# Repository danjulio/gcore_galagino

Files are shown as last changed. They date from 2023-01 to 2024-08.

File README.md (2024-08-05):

# Galagino ported to gCore
This repo is a fork of Till Harbaum's awesome [Galaga emulator](https://github.com/harbaum/galagino) ported to [gCore](https://github.com/danjulio/gCore).  It runs really well.

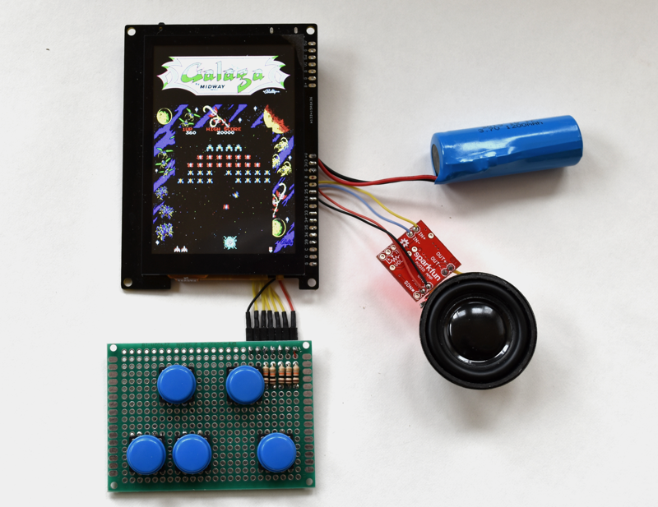
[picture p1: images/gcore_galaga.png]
Galaga on gCore


I made the following changes.

1. Changed from ILI9341 LCD driver in video.c to use my port of TFT_eSPI.
2. Changed GPIO pins for buttons (see below).
3. Added a background image around the play field.
4. Added a FAST\_FPS define to config.h to try for 60 FPS updates instead of the default 30 FPS (looked at in galingo.ino).  Add LOG\_FPS define which enables logging FPS values to the serial port.
5. Detect fast press of gCore power button to power down.
6. A little cleanup.

Compiled on Arduino 1.8.19 with ESP32 Arduino package 2.0.6.  You'll need the following libraries installed and to follow Till's original instructions below which include downloading the Z80 emulator, and finding and downloading the Galaga ROM files, then running his scripts to process them.

1. My version of [TFT_eSPI](https://github.com/danjulio/TFT_eSPI).
2. Arduino [gCore](https://github.com/danjulio/gCore/tree/main/Arduino/gCore) library.  Can also be directly downloaded from my [website](https://danjuliodesigns.com/products/gcore.html).
3. Adafruit_GFX_Library

Set the board type to WROOM.  This is to force all memory allocations to occur to ESP32 internal memory (external PSRAM is too slow for the emulator).

The hookup diagram is shown below.  You can put the buttons on a proto board as I did or you can use a breadboard as Till did.  External pull-up resistors are required since I am using GPIO34-39 (10 k-ohm is fine).  I used an [amp breakout board](https://www.sparkfun.com/products/11044) from Sparkfun but only because I had it laying around.  You can also use the amp boards Till mentions.

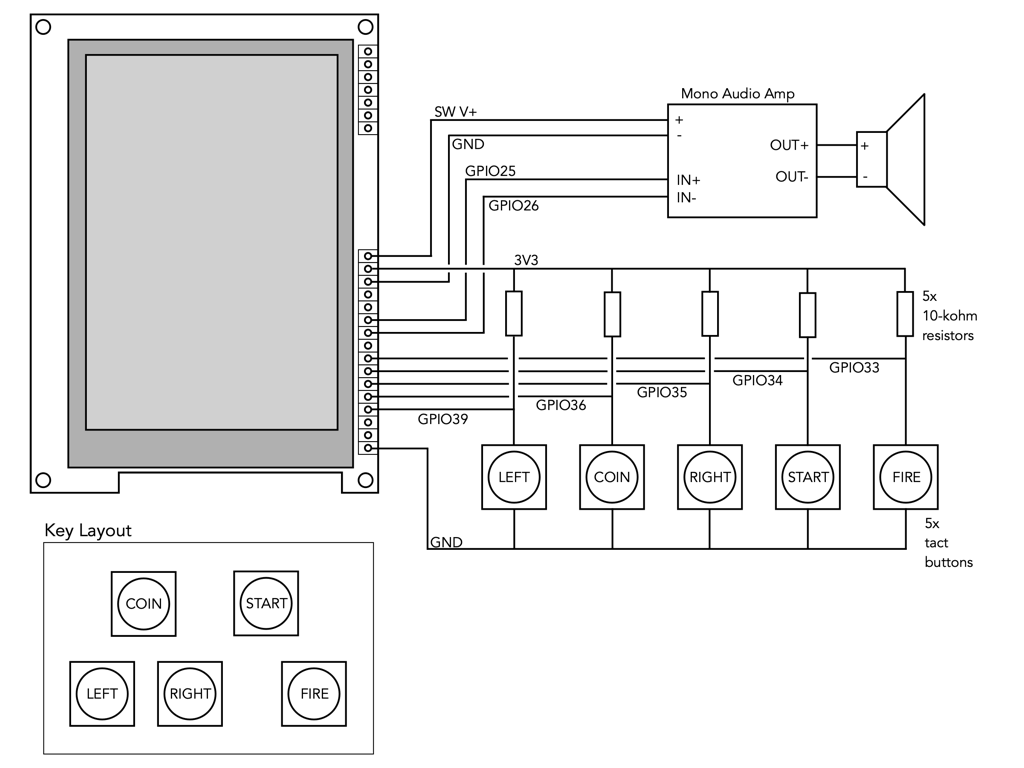
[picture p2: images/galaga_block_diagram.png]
gCore Galaga hookup diagram


## Enclosure
I used OpenSCAD to make a basic enclosure for my build.  The OpenSCAD source and STL files are in the ```enclosure``` directory.

The design also includes support for a bit of extra hardware.

1. Bulkhead USB-C connector connected to gCore's +5/GND inputs
2. Bulkhead Power button connected to gCore's SW/GND inputs
3. Bulkhead slide switch connected in series with the Audio Amp SW V+ to allow turning off the sound

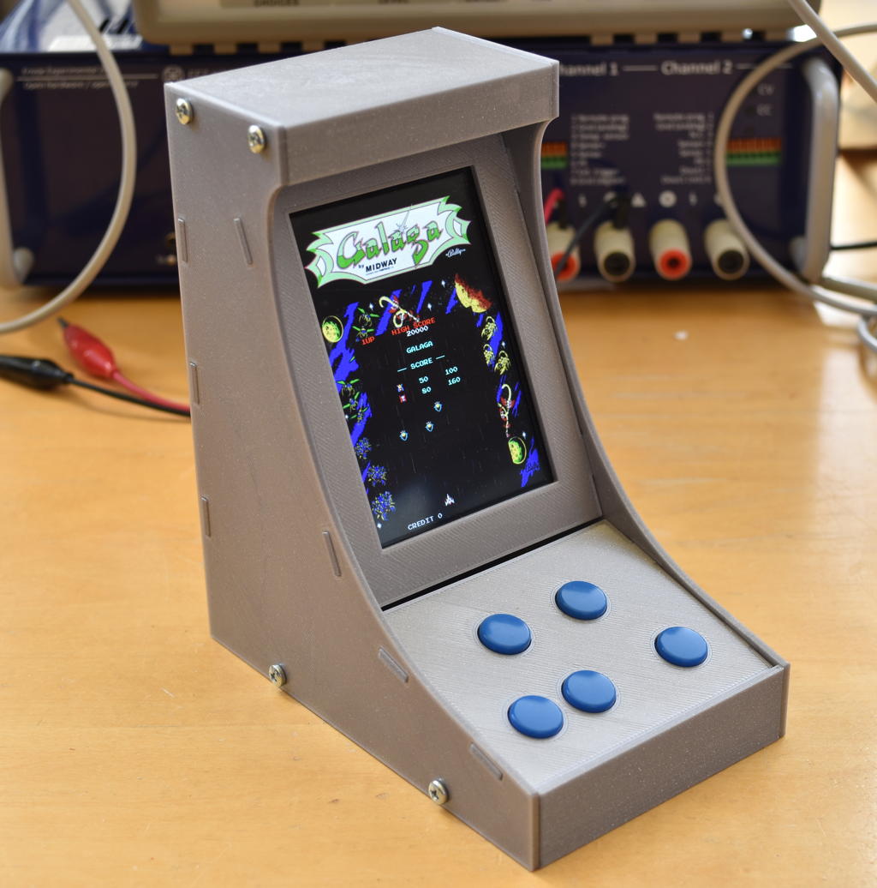
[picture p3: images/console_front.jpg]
Enclosure Front


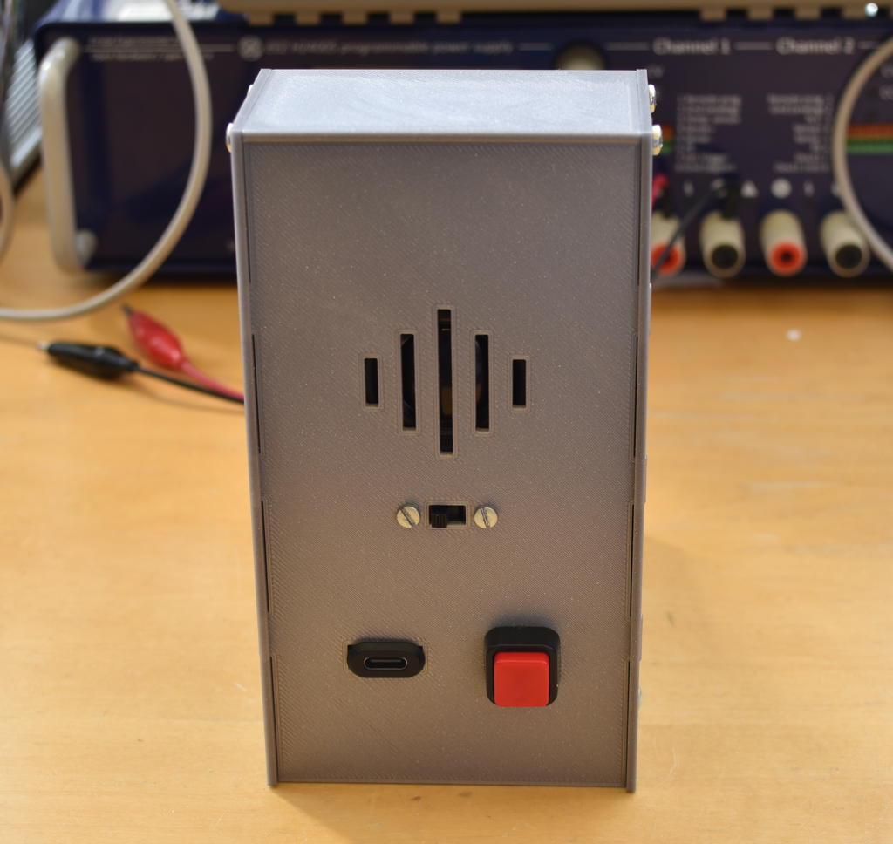
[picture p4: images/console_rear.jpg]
Enclosure Rear


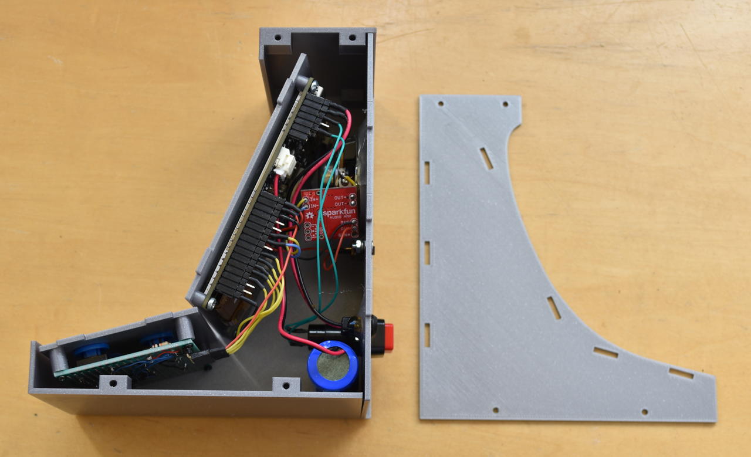
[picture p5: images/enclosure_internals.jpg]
Enclosure internals


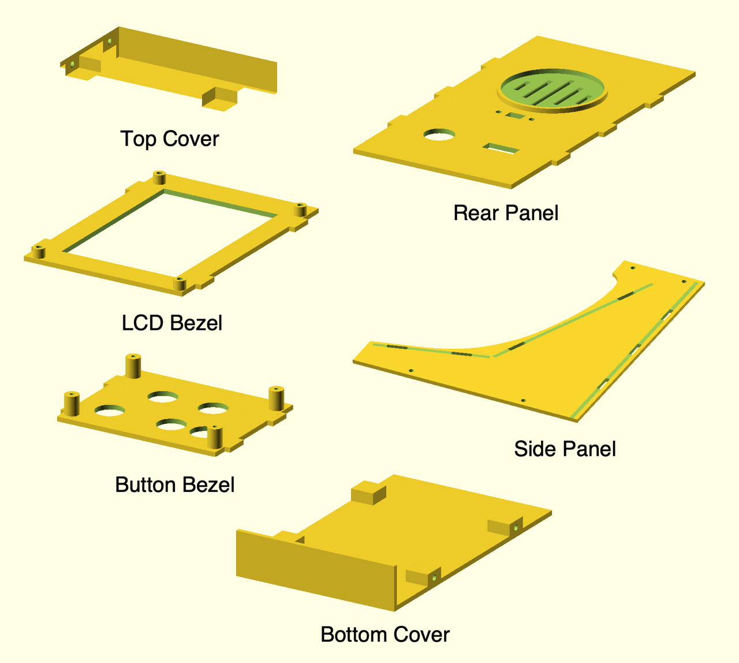
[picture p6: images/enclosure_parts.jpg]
OpenSCAD parts


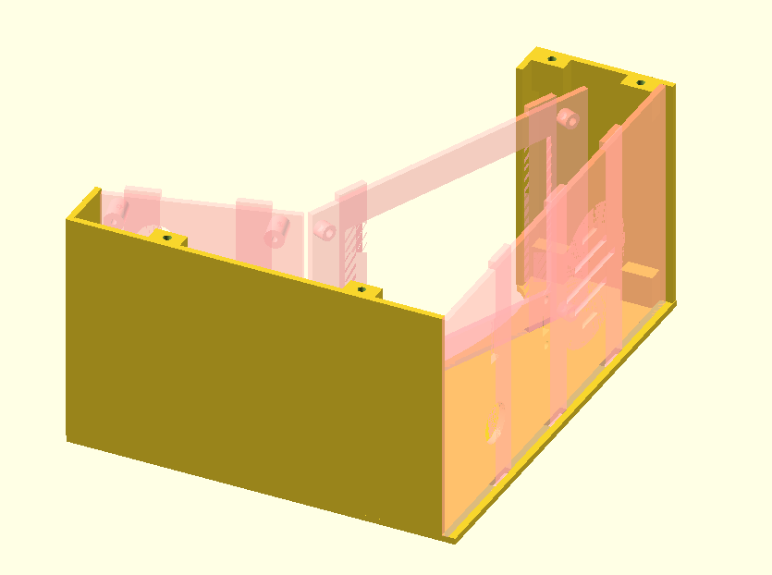
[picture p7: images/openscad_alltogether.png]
OpenSCAD altogether image


# Till Harbaum's Original Readme Below
## Galaga arcade emulator for ESP32

Galagino screencast

[Galaga](https://de.wikipedia.org/wiki/Galaga) is one of the most iconic arcade machines of all times. It has
been remade and emulated many times. So far the cheapest and smallest
system able to do a faithful emulation of the original arcade machine
was the raspberry pi. But even the much cheaper ESP32 should be able
too easily emulate a machine from the early 80's, shouldn't it?

Well, things are not that easy. The galaga arcade was driven by three
Z80 CPUs, each running at 3Mhz. Additionally the arcade machine
included two more CPUs for button and coin handling and for audio
support. And finally the hardware itself had dedicated support
for simple wavetable audio, tilemap graphics and up to 64 sprites.
The video resolution was 224 by 288 pixels. The ESP32 on the other hand
comes with two cores running at 240MHz. But it lacks dedicated video
hardware. Emulating the various CPUs as well as the handling of
audio and graphics turned out to be challenging for the ESP32.

Cheap TFT screens with a resolution of 320 by 240 pixels are available
in various sizes from 2.0 inch to 3.2 inch allowing for a very small
and cheap *galagino* setup.

These small displays usually allow for SPI clock rates of up to 40MHz
allowing for a max screen refresh rate of ~30Hz. This is exactly half
the refresh rate of the original arcade machine. 30Hz is sufficient
for a very fluid gameplay.

## Youtube videos

* [First test](https://www.youtube.com/shorts/LZRI6izM8XM)
* [Sound and Starfield working](https://www.youtube.com/shorts/8uNSv0aRtgY)
* [Finally playable](https://www.youtube.com/shorts/wqnJzOAAths)
* [Pac-Man on Galagino](https://www.youtube.com/shorts/F4-XiiPwG1c)

## Hardware

The hardware is built around one of those cheap ESP32 development
boards like the ESP32 Devkit V4 depicted in the images below. The
components needed are:

* ESP32 development board (e.g. [Devkit V4](https://www.espressif.com/en/products/devkits/esp32-devkitc))
* A 320x240 SPI TFT screen (no touch needed)
  * Either a ILI9341 based screen as depicted, or
  * a ST7789 based screen with 320x240 pixels
* An audio amplifier and speaker
  * e.g. a [PAM8302A](https://www.adafruit.com/product/2130) and a 3W speaker (as seen in the photos), or
  * a [Keyestudio SC8002B](https://www.keyestudio.com/products/keyestudio-sc8002b-audio-power-amplifier-speaker-module-for-arduino-player), or similar
* five push buttons
* breadboard and wires

The entire setup should be connected as depicted below. The Devkit is
too wide for the breadboard leaving no space above it to connect
wires. Thus the wires going to the top pin row of the Devkit are
placed underneath the DevKit with the connections done as shown in the
image below.

Breadboard scheme

Download as [Fritzing](images/galagino_bb.fzz) or [PDF](images/galagino_bb.pdf)

Breadboard photo

## Software

The software consists of three parts:

* The [Galagino specific code](galagino/) contained in this repository
* The [original Galaga Namco Rev. B ROM files](https://www.bing.com/search?q=galaga+namco+b+rom)
* A [Z80 software emulation](https://fms.komkon.org/EMUL8/Z80-081707.zip)

The ROM files have to be placed in the [roms directory](roms/), together with
the ZIP file containing the Z80 emulator. A set of [python scripts](romconv/)
is then being used to convert and patch the ROM data and emulator code and
to include the resulting code into the galagino sketch directory. These
scripts need to be run like so (this has yet only been tested under Linux,
feedback for Windows is welcome):

```
$ cd romconv
$ ./audioconv.py > ../galagino/wavetables.h
$ ./cmapconv.py > ../galagino/colormaps.h
$ ./romconv.py > ../galagino/rom.h
$ ./spriteconv.py > ../galagino/spritemap.h
$ ./tileconv.py > ../galagino/tilemap.h
$ ./tileaddr.py > ../galagino/tileaddr.h
$ ./starsets.py > ../galagino/starseed.h
$ ./z80patch.py 
Copying CodesCB.h
Copying Codes.h
Copying CodesXX.h
Copying CodesED.h
Copying CodesXCB.h
Copying Tables.h
Patching Z80.h
Patching Z80.c
$
```

Afterwards the [galagino directory](galagino) should contain the following files:

```
CodesCB.h    Codes.h      CodesXX.h    config.h     emulation.h
rom.h        starseed.h   tileaddr.h   video.cpp    wavetables.h
Z80.h        CodesED.h    CodesXCB.h   colormaps.h  emulation.c
galagino.ino spritemap.h  Tables.h     tilemap.h    video.h
Z80.c
```

With all these files in place, the galagino.ino sketch can be loaded
into the [Arduino IDE](https://docs.arduino.cc/software/ide-v2). The
Arduino IDE must have the [ESP32 board support](https://github.com/espressif/arduino-esp32)
installed and the appropriate board like e.g. the
*ESP32 Dev Module* should be selected. Finally the default core used
by Arduino should be 1 (this is the default) as Galagino will use core 0
for audio and video emulation.

## Configuration

The Galagino code can be configured through the [galagino/config.h](galagino/config.h)
file. This is also the place where it's possible to choose between the ILI9143
controller (default) and the ST7789.

Also the pin assignment can be adjusted or the TFT SPI clock.

## Improvements

Galagino runs fluid and plays perfectly. Still a few things could be optimized.

* Displays allowing for 80MHz SPI clock could run the video at full 60Hz
* The SPI display update could be done using DMA which would significantly reduce the load on ESP32 core 0
* VGA output could be used to drive a VGA screen
* The ESP32's bluetooth could be used to connect to a wireless gamepad
* Galagino could be ported to the [Raspberry Pi Pico and the DVI sock](https://picockpit.com/raspberry-pi/raspberry-pi-pico-video-output/)

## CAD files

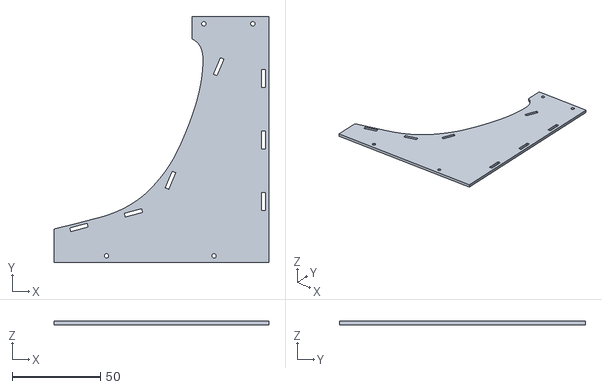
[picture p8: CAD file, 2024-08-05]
enclosure/galaga_side.stl
122.0 x 139.7 x 2.00

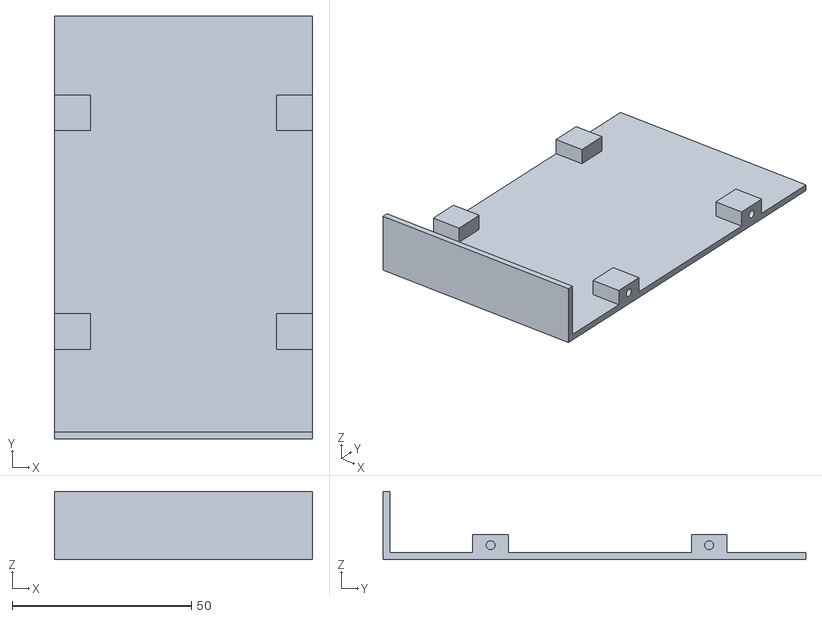
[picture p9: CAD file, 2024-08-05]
enclosure/galaga_base.stl
72.0 x 118.0 x 19.0

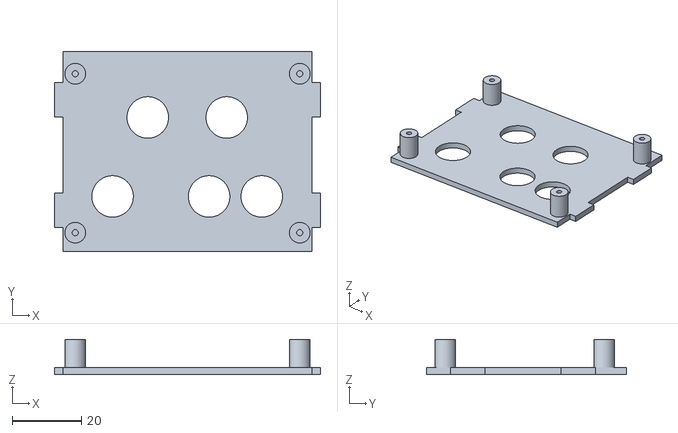
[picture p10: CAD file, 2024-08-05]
enclosure/galaga_button.stl
77.0 x 58.0 x 10.2

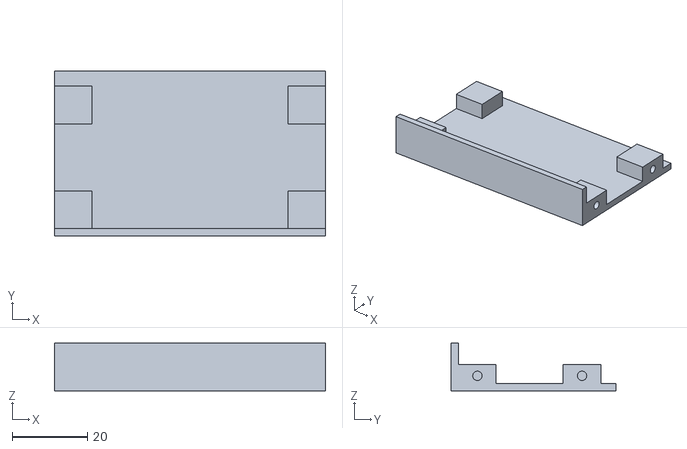
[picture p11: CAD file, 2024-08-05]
enclosure/galaga_lid.stl
72.0 x 43.8 x 12.7

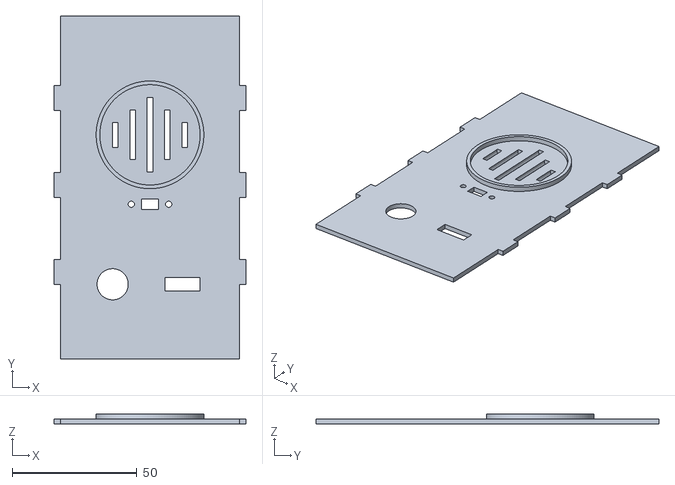
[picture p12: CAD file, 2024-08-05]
enclosure/galaga_rear.stl
77.0 x 137.7 x 4.00

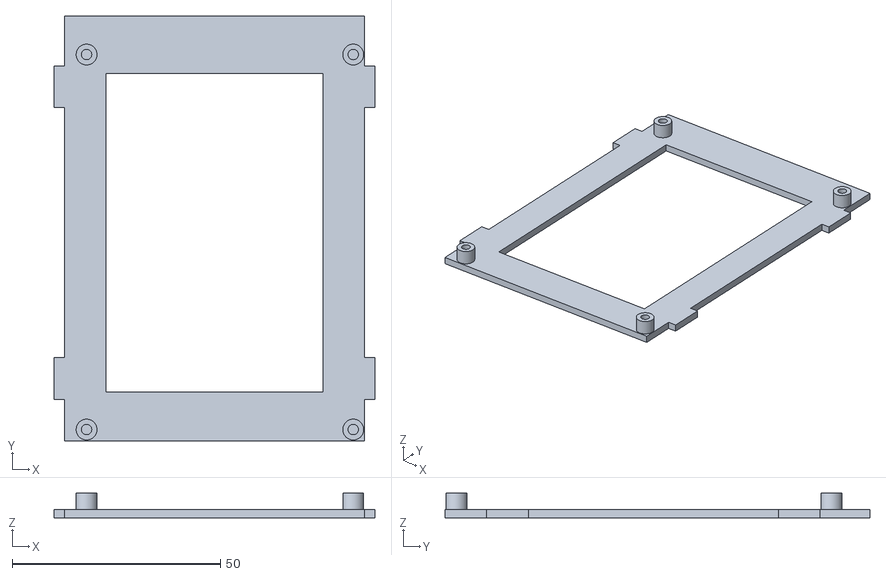
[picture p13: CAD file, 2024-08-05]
enclosure/galaga_lcd.stl
77.0 x 102.0 x 6.00

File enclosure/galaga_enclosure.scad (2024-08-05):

//
// Galaga Enclosure
//

// Render modes
//   1 raw_case_side
//   2 button_bezel
//   3 lcd_bezel
//   4 rear_panel
//   5 base
//   6 lid
//   7 case_side
//   8 all_together (one side + all other walls)
//
render_mode = 8;


module raw_case_side() {
    linear_extrude(height=2, center=false, convexity=10) {
        import(file = "case_side.svg", center=false, dpi=72);
    }
}


// PCB: 70 x 50 -> 72 x 58 (2 extra at lcd_bezel end);  Holes: 1.25 + 0.5*2.5 = 2.5
module button_bezel(slot_extra) {
    difference() {
        union() {
            cube([72, 58, 2]);
            
            // mounting tabs
            translate([-2.5, 7 - slot_extra, 0 - slot_extra]) {
                cube([77, 10 + 2*slot_extra, 2 + 2*slot_extra]);
            }
            
            translate([-2.5, 39 - slot_extra, 0 - slot_extra]) {
                cube([77, 10 + 2*slot_extra, 2 + 2*slot_extra]);
            }
            
            // Stand-offs
            translate([3.5, 5.5, 0]) {
                cylinder(r=3, h=2+8.2, $fn=120);
            }
            
            translate([72 - 3.5, 5.5, 0]) {
                cylinder(r=3, h=2+8.2, $fn=120);
            }
            
            translate([3.5, 55 - 3.5, 0]) {
                cylinder(r=3, h=2+8.2, $fn=120);
            }
            
            translate([72 - 3.5, 55 - 3.5, 0]) {
                cylinder(r=3, h=2+8.2, $fn=120);
            }
        }
        
        // screw holes
        translate([3.5, 5.5, 2]) {
            cylinder(r=0.9, h=2+ 8.3, $fn=120);
        }
        
         translate([72 - 3.5, 5.5, 2]) {
            cylinder(r=0.9, h=2+ 8.3, $fn=120);
        }
        
         translate([3.5, 55 - 3.5, 2]) {
            cylinder(r=0.9, h=2+ 8.3, $fn=120);
        }
        
         translate([72 - 3.5, 55 - 3.5, 2]) {
            cylinder(r=0.9, h=2+ 8.3, $fn=120);
        }
        
        // Button holes
        translate([14.32, 16, -0.1]) {
            cylinder(r=6, h=2.2, $fn=120);
        }
        
        translate([42.26, 16, -0.1]) {
            cylinder(r=6, h=2.2, $fn=120);
        }
        
        translate([57.5, 16, -0.1]) {
            cylinder(r=6, h=2.2, $fn=120);
        }
        
        translate([24.5, 38.86, -0.1]) {
            cylinder(r=6, h=2.2, $fn=120);
        }
        
        translate([47.36, 38.86, -0.1]) {
            cylinder(r=6, h=2.2, $fn=120);
        }
    }
}


// bezel: 72 x 102 (2 extra at top); lcd cutout: 52 x 76.5;
// lcd cutout x0  = 72/2 - 52/2 = 10
// lcd cutout y0 = 100/2 - 76.5/2 = 11.75
// screw x0 = 72/2 - 25 - 8.2 + 2.5 = 5.3
// screw y0 = 100/2 - 37.25 - 12.5 + 2.5 = 2.75
// 
module lcd_bezel(slot_extra) {
    difference() {
        union() {
            cube([72, 102, 2]);
            
            // Mounting tabs
            translate([-2.5, 10 - slot_extra, 0 - slot_extra]) {
                cube([77, 10 + 2*slot_extra, 2 + 2*slot_extra]);
            }
            
            translate([-2.5, 100 - 20 - slot_extra, 0 - slot_extra]) {
                cube([77, 10 + 2*slot_extra, 2 + 2*slot_extra]);
            }
            
            // Stand-offs
            translate([5.3, 2.75, 0]) {
                cylinder(r=2.5, h=6, $fn=120);
            }
            
            translate([5.3 + 64, 2.75, 0]) {
                cylinder(r=2.5, h=6, $fn=120);
            }
            
             translate([5.3, 2.75 + 90, 0]) {
                cylinder(r=2.5, h=6, $fn=120);
            }
            
            translate([5.3 + 64, 2.75 + 90, 0]) {
                cylinder(r=2.5, h=6, $fn=120);
            }
        }
        
        // Screw holes
        translate([5.3, 2.75, 1]) {
            cylinder(r=1.25, h=5.1, $fn=120);
        }
        
         translate([5.3 + 64, 2.75, 1]) {
            cylinder(r=1.25, h=5.1, $fn=120);
        }
        
        translate([5.3, 2.75 + 90, 1]) {
            cylinder(r=1.25, h=5.1, $fn=120);
        }
        
         translate([5.3 + 64, 2.75 + 90, 1]) {
            cylinder(r=1.25, h=5.1, $fn=120);
        }
        
        // LCD cutout
        translate([10, 11.75, -0.1]) {
            cube([52, 76.5, 2.2]);
        }
    }
}


// 70 x 139.7 (-2 at top)
module rear_panel(slot_extra) {
    difference() {
        union() {
            cube([72, 137.7, 2]);
            
            // Mounting tabs
            translate([-2.5, 139.7/4 - 5 - slot_extra, 0 - slot_extra]) {
                cube([77, 10 + 2*slot_extra, 2 + 2*slot_extra]);
            }
            
            translate([-2.5, 139.7/2 - 5 - slot_extra, 0 - slot_extra]) {
                cube([77, 10 + 2*slot_extra, 2 + 2*slot_extra]);
            }
            
            translate([-2.5, 3*139.7/4 - 5 - slot_extra, 0 - slot_extra]) {
                cube([77, 10 + 2*slot_extra, 2 + 2*slot_extra]);
            }
            
            // Speaker holder positive component
            translate([72/2, 90, 0]) {
                cylinder(d=43.25, h=4, $fn=120);
            }
        }
        
        // Power Button
        translate([21, 30, -0.1]) {
            cylinder(d=12.5, h=2.2, $fn=120);
        }
        
        // USB connector (14 x 5.5)
        translate([70 - 21 - 14/2, 30 - 5.5/2, -0.1]) {
            cube([14, 5.5, 2.2]);
        }
        
        // Speaker holder negative component
        translate([72/2, 90, 2]) {
            cylinder(d=40.25, h=4, $fn=120);
        }
        
        // Speaker grill
        translate([22, 90 - 10/2, 1]) {
            rotate([-90, 0, 0]) {
                cylinder(d=3, h=10, $fn=30);
            }
        }
        
        translate([29, 90 - 20/2, 1]) {
            rotate([-90, 0, 0]) {
                cylinder(d=3, h=20, $fn=30);
            }
        }
        
        translate([36, 90- 30/2, 1]) {
            rotate([-90, 0, 0]) {
                cylinder(d=3, h=30, $fn=30);
            }
        }
        
        translate([43, 90 - 20/2, 1]) {
            rotate([-90, 0, 0]) {
                cylinder(d=3, h=20, $fn=30);
            }
        }
        
        translate([50, 90 - 10/2, 1]) {
            rotate([-90, 0, 0]) {
                cylinder(d=3, h=10, $fn=30);
            }
        }
        
        // Speaker power switch
        // 15 between 2.75 diameter holes; 7x4.25 cutout
        translate([(72 - 7)/2, 60, -0.1]) {
            cube([7, 4.25, 2.2]);
        }
        
        translate([(72 - 15)/2, 62.125, -0.1]) {
            cylinder(d=2.5, h=2.2, $fn=120);
        }
        
        translate([(72 + 15)/2, 62.125, -0.1]) {
            cylinder(d=2.5, h=2.2, $fn=120);
        }
    }
}


// bottom: 72 x (122-4) x 2
// front face: 70 x 19.05 x 2
module base() {
    difference() {
        union() {
            // bottom
            cube([72, 122 - 4, 2]);
            
            // front face
            cube([72, 2, 19]);
            
            // mounting blocks
            translate([0, 25, 0]) {
                cube([10, 10, 7]);
            }
            
            translate([0, 86, 0]) {
                cube([10, 10, 7]);
            }
            
            translate([72 - 10, 25, 0]) {
                cube([10, 10, 7]);
            }
            
            translate([72 - 10, 86, 0]) {
                cube([10, 10, 7]);
            }
        }
        
        // screw holes
        translate([-0.1, 25 + 5, 4]) {
            rotate([0, 90, 0]) {
                cylinder(r=1.25, h=8, $fn=60);
            }
        }
        
        translate([-0.1, 86 + 5, 4]) {
            rotate([0, 90, 0]) {
                cylinder(r=1.25, h=8, $fn=60);
            }
        }
        
        translate([72.1, 25 + 5, 4]) {
            rotate([0, -90, 0]) {
                cylinder(r=1.25, h=8, $fn=60);
            }
        }
        
        translate([72.1, 86 + 5, 4]) {
            rotate([0, -90, 0]) {
                cylinder(r=1.25, h=8, $fn=60);
            }
        }
    }
}
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

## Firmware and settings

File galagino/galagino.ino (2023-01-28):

/*
 * galagino.ino - Galaga arcade for ESP32 and Arduino IDE ported to gCore
 *
 * 
 *
 */
#include "gCore.h"
#include "driver/i2s.h"
#include "video.h"
#include "emulation.h"

// include converted rom data
#include "tilemap.h"
#include "spritemap.h"
#include "colormaps.h"
#include "tileaddr.h"
#include "wavetables.h"

#include "config.h"

gCore gc;
Video tft = Video();

// buffer space for one row of 28 characters
unsigned short *frame_buffer;

TaskHandle_t videotask;

// the hardware supports 64 sprites
unsigned char active_sprites = 0;
struct sprite_S {
  unsigned char code, color, flags;
  short x, y; 
} *sprite;

struct star { unsigned char y, x; unsigned short col; };
#include "starseed.h"
unsigned char stars_scroll_y = 0;

// the ship explosion sound is stored as a digi sample.
// All other souunds are generated on the fly via the
// original wave tables
unsigned short snd_boom_cnt = 0;
const signed char *snd_boom_ptr = NULL;

void prepare_frame(void) {
  // Do all the preparations to render a screen.
  
  /* preprocess sprites */
  active_sprites = 0;
  for(int idx=0;idx<64 && active_sprites<92;idx++) {
    unsigned char *sprite_base_ptr = memory + 2*(63-idx);
    // check if sprite is visible
    if ((sprite_base_ptr[0x1b80 + 1] & 2) == 0) {
      struct sprite_S spr;     
      
      spr.code = sprite_base_ptr[0x0b80];
      spr.color = sprite_base_ptr[0x0b80 + 1];
      spr.flags = sprite_base_ptr[0x1b80];
      // adjust sprite position on screen for upright screen
      spr.x = sprite_base_ptr[0x1380] - 16;
      spr.y = sprite_base_ptr[0x1380 + 1] +
	      0x100*(sprite_base_ptr[0x1b80 + 1] & 1) - 40;

      if((spr.code < 128) &&
    	   (spr.y > -16) && (spr.y < 288) &&
	       (spr.x > -16) && (spr.x < 224)) {      

    	  // save sprite in list of active sprites
	      sprite[active_sprites] = spr;
      	// for horizontally doubled sprites, this one becomes the code + 2 part
	      if(spr.flags & 0x08) sprite[active_sprites].code += 2;	
	      active_sprites++;
      }

      // handle horizontally doubled sprites
      if((spr.flags & 0x08) &&
    	   (spr.y > -16) && (spr.y < 288) &&
    	   ((spr.x+16) >= -16) && ((spr.x+16) < 224)) {
	      // place a copy right to the current one
	      sprite[active_sprites] = spr;
	      sprite[active_sprites].x += 16;
	      active_sprites++;
      }

      // handle vertically doubled sprites
      // (these don't seem to happen in galaga)
      if((spr.flags & 0x04) &&
	       ((spr.y+16) > -16) && ((spr.y+16) < 288) && 
	      (spr.x > -16) && (spr.x < 224)) {      
	      // place a copy below the current one
	      sprite[active_sprites] = spr;
	      sprite[active_sprites].code += 3;
	      sprite[active_sprites].y += 16;
	      active_sprites++;
      }
	
      // handle in both directions doubled sprites
      if(((spr.flags & 0x0c) == 0x0c) &&
	       ((spr.y+16) > -16) && ((spr.y+16) < 288) &&
	       ((spr.x+16) > -16) && ((spr.x+16) < 224)) {
	      // place a copy right and below the current one
	      sprite[active_sprites] = spr;
	      sprite[active_sprites].code += 1;
	      sprite[active_sprites].x += 16;
	      sprite[active_sprites].y += 16;
	      active_sprites++;
      }
    }
  }
}

void render_stars_set(short row, const struct star *set) {    
  for(char star_cntr = 0;star_cntr < 63 ;star_cntr++) {
    const struct star *s = set+star_cntr;

    unsigned short x = (244 - s->x) & 0xff;
    unsigned short y = ((s->y + stars_scroll_y) & 0xff) + 16 - row * 8;

    if(y < 8 && x < 224)
      frame_buffer[224*y + x] = s->col;
  }     
}

// draw a single 8x8 tile
void blit_tile(short row, char col) {
  unsigned short addr = tileaddr[row][col];

  // skip blank tiles (0x24) in rendering  
  if(memory[addr] == 0x24) return;
    
  const unsigned short *tile = gg1_9[memory[addr]];
  const unsigned short *colors = prom_4[memory[0x400 + addr] & 63];
    
  unsigned short *ptr = frame_buffer + 8*col;

  // 8 pixel rows per tile
  for(char r=0;r<8;r++,ptr+=(224-8)) {
    unsigned short pix = *tile++;
    // 8 pixel columns per tile
    for(char c=0;c<8;c++,pix>>=2) {
      if(pix & 3) *ptr = colors[pix&3];
      ptr++;
    }
  }
}

// render a single 16x16 sprite. This is called multiple times for
// double sized sprites. This renders onto a single 224 x 8 tile row
// thus will be called multiple times even for single sized sprites
void blit_sprite(short row, unsigned char s) {
  const unsigned long *spr = gg1_10[sprite[s].flags & 3][sprite[s].code];
  const unsigned short *colors = prom_3[sprite[s].color & 63];

  // create mask for sprites that clip left or right
  unsigned long mask = 0xffffffff;
  if(sprite[s].x < 0)      mask <<= -2*sprite[s].x;
  if(sprite[s].x > 224-16) mask >>= (2*(sprite[s].x-(224-16)));		

  short y_offset = sprite[s].y - 8*row;

  // check if there are less than 8 lines to be drawn in this row
  unsigned char lines2draw = 8;
  if(y_offset < -8) lines2draw = 16+y_offset;

  // check which sprite line to begin with
  unsigned short startline = 0;
  if(y_offset > 0) {
    startline = y_offset;
    lines2draw = 8 - y_offset;
  }

  // if we are not starting to draw with the first line, then
  // skip into the sprite image
  if(y_offset < 0)
    spr -= y_offset;  

  // calculate pixel lines to paint  
  unsigned short *ptr = frame_buffer + sprite[s].x + 224*startline;
  
  // 16 pixel rows per sprite
  for(char r=0;r<lines2draw;r++,ptr+=(224-16)) {
    unsigned long pix = *spr++ & mask;
    // 16 pixel columns per tile
    for(char c=0;c<16;c++,pix>>=2) {
      if(pix & 3)
	      *ptr = colors[pix&3];
      ptr++;
    }
  }
}

// render one of 36 tile rows (8 x 224 pixel lines)
void render_line(short row) {
  // clear buffer for black background  
  memset(frame_buffer, 0, 2*224*8);

  if(starcontrol & 0x20) {
    /* two sets of stars controlled by these bits */
    render_stars_set(row, star_set[(starcontrol & 0x08)?1:0]);
    render_stars_set(row, star_set[(starcontrol & 0x10)?3:2]);
  }

  // render sprites
  for(unsigned char s=0;s<active_sprites;s++) {
    // check if sprite is visible on this row
    if((sprite[s].y < 8*(row+1)) && ((sprite[s].y+16) > 8*row))
      blit_sprite(row, s);
  }

  // render 28 tile columns per row
  for(char col=0;col<28;col++)
    blit_tile(row, col);
}

void snd_trigger_explosion(void) {
  snd_boom_cnt = 2*sizeof(boom);
  snd_boom_ptr = boom;
}
  
static unsigned long snd_cnt[3] = { 0,0,0 };
static unsigned long snd_freq[3];
static const signed char *snd_wave[3];
static unsigned char snd_volume[3];
#ifdef SND_DIFF
static unsigned short snd_buffer[128]; // buffer space for two channels
#else
static unsigned short snd_buffer[64];  // buffer space for a single channel
#endif

void snd_render_buffer(void) {
  // render first buffer contents
  for(int i=0;i<64;i++) {
    short v = 0;
    // add up to three wave signals
    if(snd_volume[0]) v += snd_volume[0] * snd_wave[0][(snd_cnt[0]>>14) & 0x1f];
    if(snd_volume[1]) v += snd_volume[1] * snd_wave[1][(snd_cnt[1]>>14) & 0x1f];
    if(snd_volume[2]) v += snd_volume[2] * snd_wave[2][(snd_cnt[2]>>14) & 0x1f];
      
    if(snd_boom_cnt) {
      v += *snd_boom_ptr;
      if(snd_boom_cnt & 1) snd_boom_ptr++;
      snd_boom_cnt--;
    }
    
    // v is now max 3*15*(15-7)+127 = 487 and min 3 * 15 * (0-7) - 128 = -443
    // expand to +/- 15 bit
    v = v*64;

#ifdef SND_DIFF
    // generate differential output
    snd_buffer[2*i]   = 0x8000 + v;    // positive signal on GPIO26
    snd_buffer[2*i+1] = 0x8000 - v;    // negatve signal on GPIO25 
#else
    snd_buffer[i]     = 0x8000 + v;
#endif
      
    snd_cnt[0] += snd_freq[0];
    snd_cnt[1] += snd_freq[1];
    snd_cnt[2] += snd_freq[2];
  }
}

void snd_prepare(void) {
  // parse all three wsg channels
  for(char ch=0;ch<3;ch++) {  
    // channel volume
    snd_volume[ch] = soundregs[ch * 5 + 0x15];
    
    if(snd_volume[ch]) {
      // frequency
      snd_freq[ch] = (ch == 0) ? soundregs[0x10] : 0;
      snd_freq[ch] += soundregs[ch * 5 + 0x11] << 4;
      snd_freq[ch] += soundregs[ch * 5 + 0x12] << 8;
      snd_freq[ch] += soundregs[ch * 5 + 0x13] << 12;
      snd_freq[ch] += soundregs[ch * 5 + 0x14] << 16;

      // wavetable entry
      snd_wave[ch] = wavetables[soundregs[ch * 5 + 0x05] & 0x07];
    }
  }

  // render first buffer contents
  // snd_render_buffer();
}

void snd_transmit() {
  // (try to) transmit as much audio data as possible. Since we
  // write data in exact the size of the DMA buffers we can be sure
  // that either all or nothing is actually being written
  
  size_t bytesOut = 0;
  do {
    // copy data in i2s dma buffer if possible
    i2s_write(I2S_NUM_0, snd_buffer, sizeof(snd_buffer), &bytesOut, 0);

    // render the next audio chunk if data has actually been sent
    if(bytesOut) {
      snd_prepare();
      snd_render_buffer();
    }

//    printf("WR %ld\n", bytesOut);
  } while(bytesOut);
}

void update_screen(void) {
  uint32_t t = micros();
  
  prepare_frame();
  
  // 8*224 pixels = 8*224*16 = 28672 bits
  // 2790 char rows per sec at 40Mhz = max 38 fps
  for(int c=0;c<36;c+=4) {
    render_line(c+0); tft.write(frame_buffer, 224*8);
    render_line(c+1); tft.write(frame_buffer, 224*8);
    render_line(c+2); tft.write(frame_buffer, 224*8);
    render_line(c+3); tft.write(frame_buffer, 224*8);
    
    // audio is refilled 18 times per screen update. The screen is updated
    // every second frame. So audio is refilled every 9 times per frame.
    // Audio registers are udated by CPU3 two times per frame.
    snd_transmit();
  } 

  /* the screen is only updated every second frame, scroll speed is thus doubled */
  static const signed char speeds[8] = { -1, -2, -3, 0, 3, 2, 1, 0 };
  stars_scroll_y += 2*speeds[starcontrol & 7];
  
  // one screen at 60 Hz is 16.67ms
  // -> one screen at 30 Hz is 33.33ms   
  t = (micros()-t)/1000;  // calculate time in milliseconds
#ifdef FAST_FPS
  if(t<17) vTaskDelay(17-t);
#else
  if(t<33) vTaskDelay(33-t);
#endif
  else     vTaskDelay(1);    // at least 1 ms delay to prevent watchdog timeout
  
//  printf("uspf %d\n", t);
}

void video(void *p) {
  esp_err_t ret;
  int chk_cnt = 0;
#ifdef LOG_FPS
  unsigned long start_t = 0;
  unsigned long end_t = 0;
  int fps;
#endif
  
  tft.begin();

  // init audio
  // 24 kHz @ 16 bit = 48000 bytes/sec = 800 bytes per 60hz game frame =
  // 1600 bytes per 30hz screen update = ~177 bytes every four tile rows  
  static const i2s_config_t i2s_config = {
    .mode = (i2s_mode_t)(I2S_MODE_MASTER | I2S_MODE_TX | I2S_MODE_DAC_BUILT_IN),
    .sample_rate = 24000,
    .bits_per_sample = I2S_BITS_PER_SAMPLE_16BIT,
#ifdef SND_DIFF
    .channel_format = I2S_CHANNEL_FMT_RIGHT_LEFT,
#else
    .channel_format = I2S_CHANNEL_FMT_ONLY_LEFT,
#endif
//    .communication_format = (i2s_comm_format_t)I2S_COMM_FORMAT_I2S_MSB,
    .communication_format = I2S_COMM_FORMAT_STAND_MSB,
    .intr_alloc_flags = 0,
    .dma_buf_count = 4,
    .dma_buf_len = 64,   // 64 samples
    .use_apll = false
  };

  snd_prepare();
  snd_render_buffer();
  i2s_driver_install(I2S_NUM_0, &i2s_config, 0, NULL);
  // use dac on default gpio25/26
//  i2s_set_pin(I2S_NUM_0, NULL);
  i2s_set_dac_mode(I2S_DAC_CHANNEL_BOTH_EN);
//  i2s_start(I2S_NUM_0);

  while(1) {
    update_screen();

    // Periodically check for power off button press and [optionally] update FPS
    if ((++chk_cnt % 30) == 0) {
      if (gc.power_button_pressed()) {
        gc.power_off();
      }
#ifdef LOG_FPS
      end_t = millis();
      fps = round((30 * 1000.0) / (end_t - start_t));
      start_t = end_t;
      Serial.printf("%d FPS\n", fps);
#endif
    }
  }
}

void setup() {
  Serial.begin(115200);
  Serial.println();
  Serial.println("Galagino");

  // Setup gCore
  gc.begin();
  gc.power_set_brightness(100);
  gc.power_set_button_short_press_msec(100);

  // this should not be needed as the CPU runs by default on 240Mht nowadays
  setCpuFrequencyMhz(240000000);

  Serial.print("Free heap: "); Serial.println(ESP.getFreeHeap());
  Serial.print("Main core: "); Serial.println(xPortGetCoreID());
  Serial.print("Main priority: "); Serial.println(uxTaskPriorityGet(NULL));  

  // allocate memory for a single tile/character row
  frame_buffer = (unsigned short*)malloc(224*8*2);
  sprite = (struct sprite_S*)malloc(96 * sizeof(struct sprite_S));
  Serial.print("Free heap: "); Serial.println(ESP.getFreeHeap());
  
  // make button pins inputs
  pinMode(BTN_START_PIN, INPUT);
  pinMode(BTN_COIN_PIN, INPUT);
  pinMode(BTN_LEFT_PIN, INPUT);
  pinMode(BTN_RIGHT_PIN, INPUT);
  pinMode(BTN_FIRE_PIN, INPUT);

  prepare_emulation();
  // while(!game_started) emulate_frame();

  // let the video processing run on the second core, so the main core
  // can completely focus on emulation
  xTaskCreatePinnedToCore(
      video, /* Function to implement the task */
      "Video task", /* Name of the task */
      4096,  /* Stack size in words */
      NULL,  /* Task input parameter */
      2,  /* Priority of the task */
      &videotask,  /* Task handle. */
      0); /* Core where the task should run */
}

unsigned char buttons_get(void) {
  return 
    (digitalRead(BTN_START_PIN)?0:KEYCODE_1) |
    (digitalRead(BTN_COIN_PIN)?0:KEYCODE_3) |
    (digitalRead(BTN_LEFT_PIN)?0:KEYCODE_LEFT) |
    (digitalRead(BTN_RIGHT_PIN)?0:KEYCODE_RIGHT) |
    (digitalRead(BTN_FIRE_PIN)?0:KEYCODE_FIRE);
}

void loop(void) {
  // the main task runs the emulation of the three main CPUs
  emulate_frame();
}

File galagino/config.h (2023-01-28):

#ifndef _CONFIG_H_
#define _CONFIG_H_

// game config
//#define FREEPLAY     // define for free play, no coin button required, but also no attract mode

// update rate - undefine to try 60 Hz instead of 30 Hz
#define FAST_FPS

// Log FPS - undefine to print FPS to serial
//#define LOG_FPS

// x and y offset of 224x288 pixels at the middle bottom of the 320x480 screen
#define TFT_X_OFFSET 48
#define TFT_Y_OFFSET 192

// audio config
#define SND_DIFF   // set to output differential audio on GPIO25 _and_ inverted on GPIO26

// pins used for buttons
#define BTN_START_PIN  34
#define BTN_COIN_PIN   36
#define BTN_LEFT_PIN   39
#define BTN_RIGHT_PIN  35
#define BTN_FIRE_PIN   33

#endif // _CONFIG_H_

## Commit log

2023-01-28 Added LOG_FPS
    Also fixed a bug in the timer detecting power off
    [config.h, galagino.ino]
2024-08-05 Added enclosure
    [galaga_base.stl, galaga_button.stl, galaga_enclosure.scad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]
